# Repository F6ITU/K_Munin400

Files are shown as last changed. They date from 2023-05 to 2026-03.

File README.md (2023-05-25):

# K_Munin400
LA2NI's OpenHPSDR 400W HF amplifier (Kicad Version)

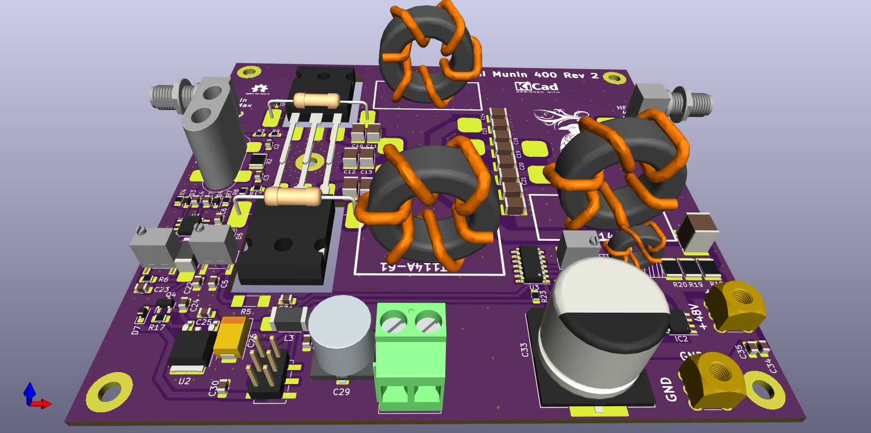
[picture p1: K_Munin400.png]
Munin, a 400W HF linear amplifier


This amplifier board is part of a set consisting of a 400 W LD-Mos based RF power amplifier (Munin 400), 
a medium power Zolotarev low pass filter (600 or 1500 W), an Automatic Antenna Tuner (ATU) nickname « Aries » 
and a 4 port antenna switch.

All these developments are the work and intellectual property of Kjell Karlsen LA2NI and Laurence Barker G8NJJ.

This original work can be downloaded from

https://github.com/LA2NI/

https://github.com/laurencebarker

This board was originally developed in December 2021 by Kjell LA2NI , with UltiBoard EDA. This repository is a « bug for bug »
clone of the original amplifier using the Opensource Kicad EDA. 
All these KiCad files are, consequently, the intellectual property of Kjell LA2NI.

This portage (convertion/translation) is placed under the CERN Open source/ Open hardware Licence.

Kicad is an Opensource EDA software maintained by the European Reseach Center CERN (Conseil européen pour la recherche nucléaire)

The original work is protected by the TAPR Open Hardware licence

Munin and Hugin are the two "messenger" ravens of the Norse god Odin - just as Hermes is the messenger-god in Greek mythology, 
and the masterpiece of the OpenHPSDR architecture 

This LDMoS transistor-based amplifier brings speech over the great distances of the "Midgard" of the waves

# Work in progress
do NOT use these files as long as this footnote hasn't been deleted

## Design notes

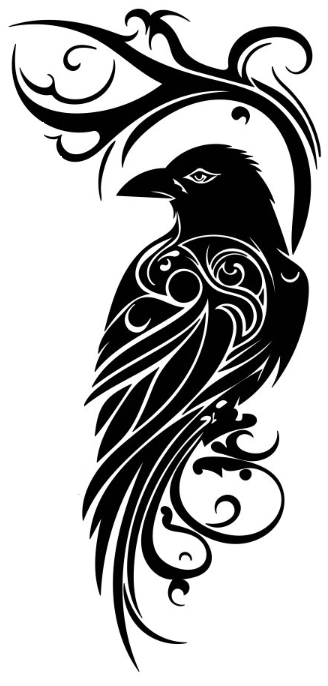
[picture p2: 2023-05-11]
Documentation/munin.bmp

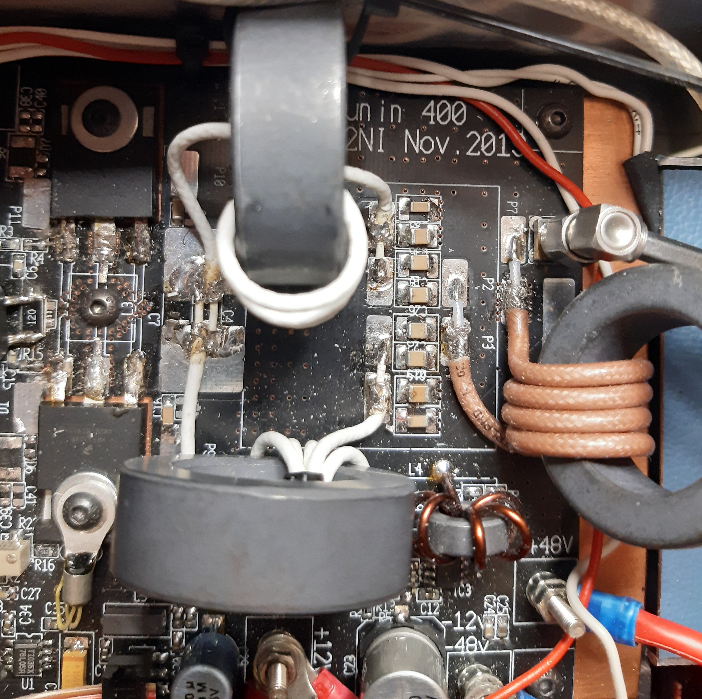
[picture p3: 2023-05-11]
Documentation/Ampli_kjell1.jpg

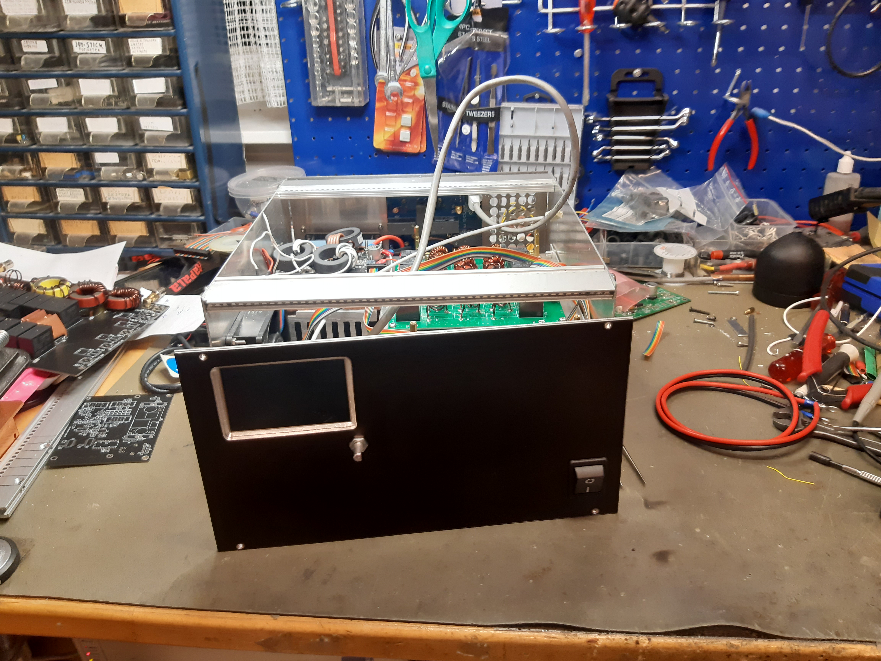
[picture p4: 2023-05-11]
Documentation/Ampli_kjell_2.jpg

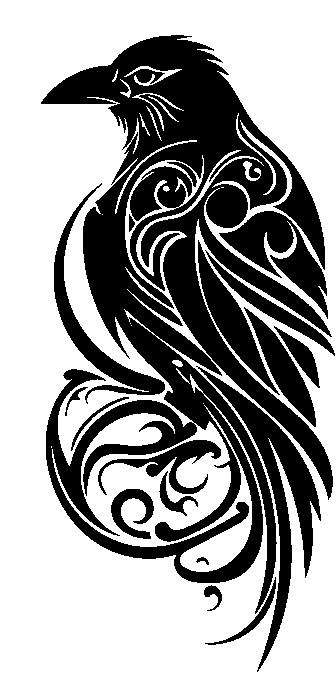
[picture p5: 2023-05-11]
Documentation/hugin.bmp

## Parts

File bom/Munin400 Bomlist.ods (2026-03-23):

Composant | Valeur | Taille | Référence Mouser | Référence Farnell | Référence RS | Référence TME
C1, C2, C12, C13, C17, C32, C34, C35 | 1μ | 0805 | 963-MJ212DC7105MGHTE | 1414042 | 192-7661
C10, C11, C19, C5, C27, C30, C31 | 100nf | 0805 |  | 1833888 | 264-4416
C14 | 22μ/63V |  | 81-KRM55WR71J226MH1K | 1850125
C18, C19, C22, C26 | 100nf haute bourre | 1812 | 810-C4532C0G2E104KKN | délais longs | 169-6642
C23 | 330μ /63V |  | 594-MAL214699809E3 | 3265775
C24, C32 | 1μ/100V | 0805 | 963-MJ212DC7105MGHTE | pas trouvé en 0805
C25 | 100nf/100V | 0805 | 581-FS051C104K4Z2A | 1907331
C28 | 10μ/35V | 2220 | 581-2220DC106MAT2A | 9697012
C29 | 220μ/25V |  | 661-HHXF250ARA221MHA | 1834209
C3, C16 | 10nf/250V | 1210
C33, C36, C20, C21 | 100nf décloupage transfos | 1812 | 810-C4532C0G2E104KKN
C6, C15, C37 | 10nf | 0805
C9, C42 | 1μ/250v | 0805
D1, D2, D5 | BAS16J |  | 771-BAS16J115 | délais longs | 166-0036 en rupture
D7, D6 | CDSOD323-TC03
D8 | CDSOD323-TC15C
IC1 | LM358N |  | 926-LM358AMX/NOPB
IC3 | ACHS-7123
J2, J8 | SMA femelle
L4 | Tore 61 |  | Rota Franco
L7, L5 | 27430211447 |  | 623-2743021447LF
R1, R22 | Potar 10k |  | TS53YJ 10K 20%TR
R12, R21 | 220R | 1206
R13, R25 | 10k | 0805 |  |  | 565-948
R14 | NTC 10K |  | 594-NTCALUG02A103F
R16 | 6k8 |  |  |  | 666-2584
R18, R19, R20 | 4R7 | 1206 |  |  | 721-8655
R2 | 1k2 | 0805 |  |  | 662-0455
R23 | potar 1K
R24 | 100 R | 0805 |  |  | pas dispo
R3, R17 | 22R | 0805 |  |  | pas dispo
R4, R15 | 1R | 0805
R5 | 27k | 0805
R7, R9, R10, R11, R26, R27 | 470/3W
R8 | 5R6 | 1812
T4, T5, T6 | FT-114U-61-A |  | compat. Fair-Rite 5961001201 | 5961001201 | 5961001201 mouser
TR1 | MRF300AN |  | 771-MRF300AN
TR2 | MRF300BN |  | 771-MRF300BN
TR3 | BSS84 |  |  |  | 166-0053
U1 | 78L05 |  | 595-UA78L05CDRE4 à vérifier brochage |  | 688-9313
U2 | LMC660 |  | longs délais | longs délais dispo chez Reichelt | 460-572 | LMC660AIM/NOPB
SMA femelle coudée |  |  |  |  | 878-2413
Connecteur J3 |  |  | 855-M20-8760342R
 | 01/23

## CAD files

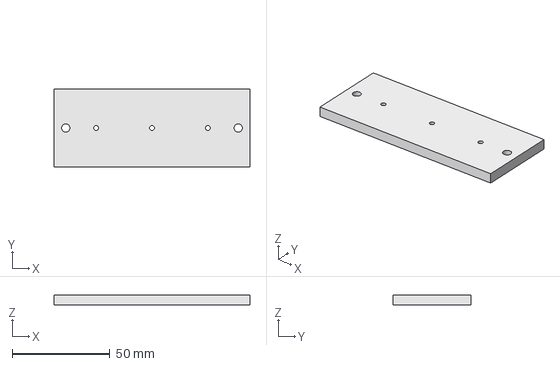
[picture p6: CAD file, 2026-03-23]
Documentation/copper_heat_spreader.FCStd
100.0 x 40.0 x 5.00 mm

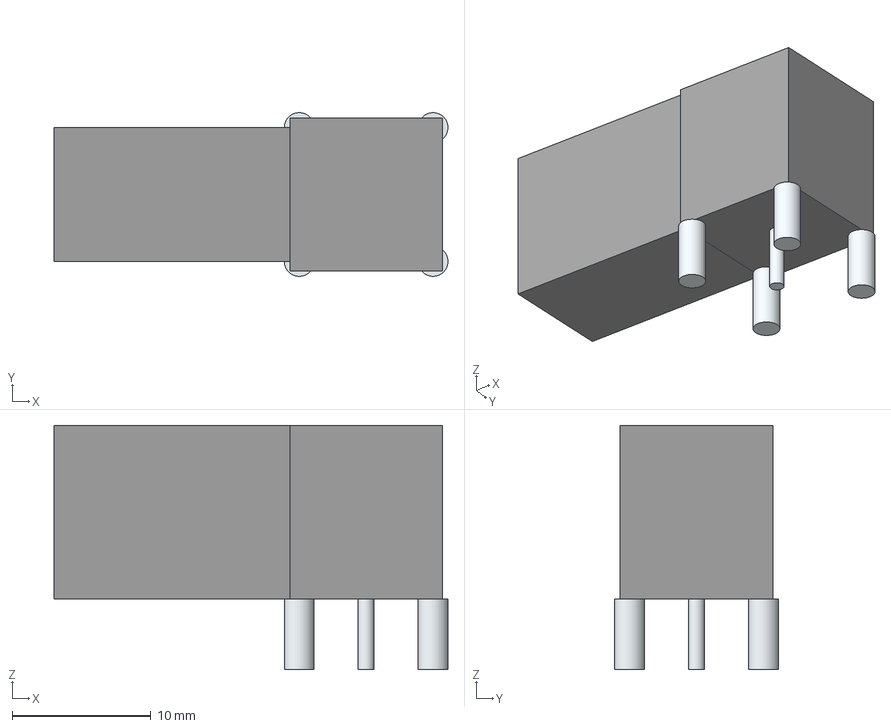
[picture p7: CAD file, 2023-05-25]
Documentation/TNC PCB/73204-5213/3D/73204-5213.stp
28.4 x 11.8 x 17.6 mm
Leads x 5

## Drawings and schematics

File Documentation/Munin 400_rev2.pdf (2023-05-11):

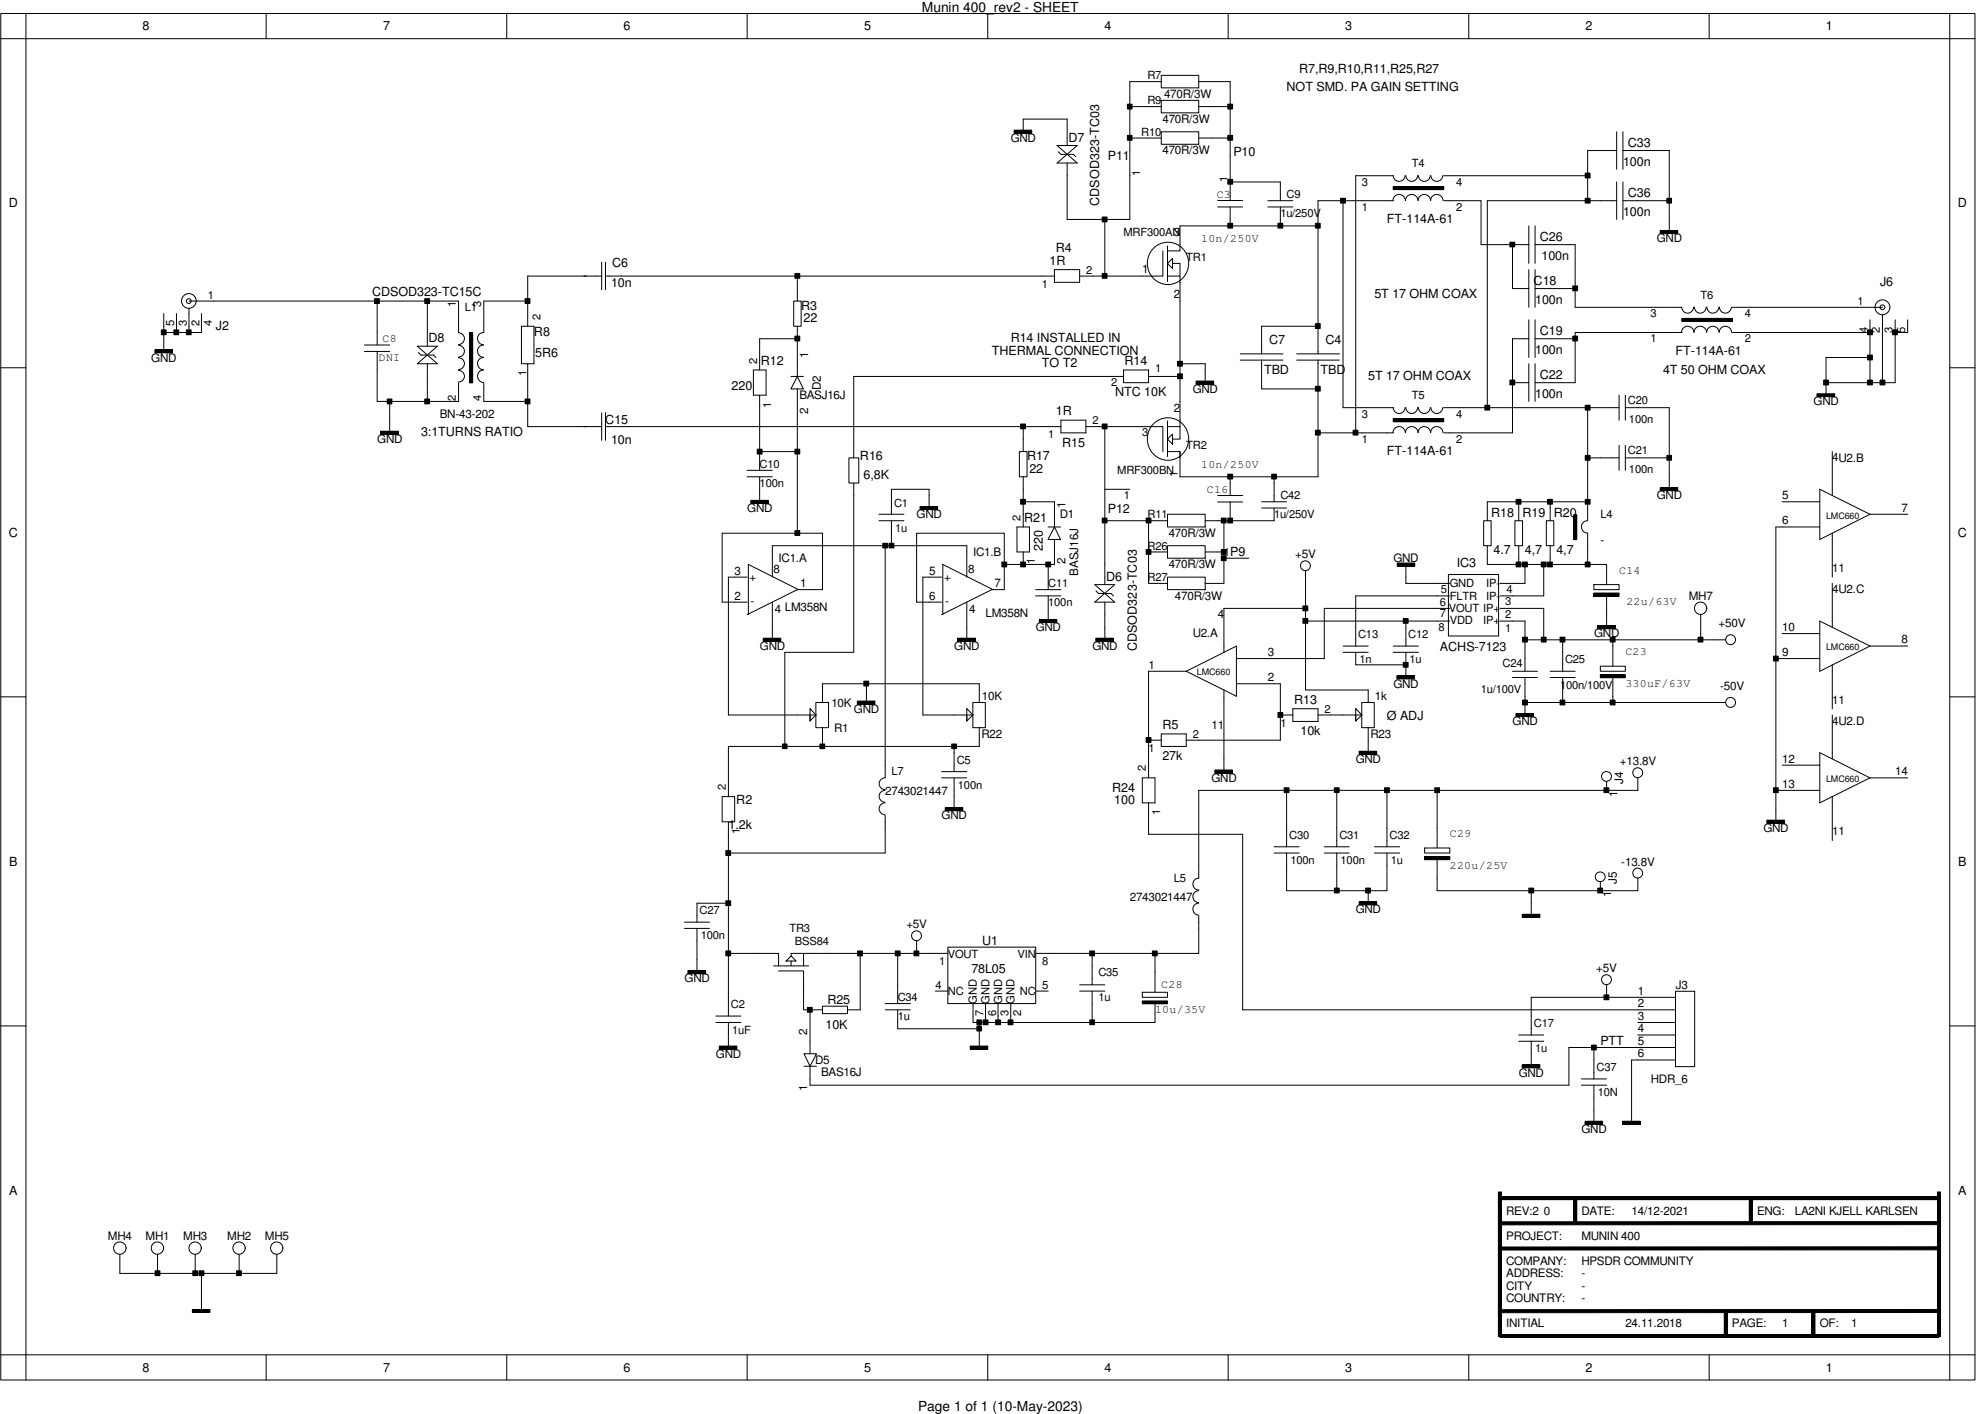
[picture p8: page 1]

NOT SMD. PA GAIN SETTING

1 IP+ 2 IP+ 3 IP- 4 IP- 5 GND 6 FLTR 7 VOUT 8 VDD

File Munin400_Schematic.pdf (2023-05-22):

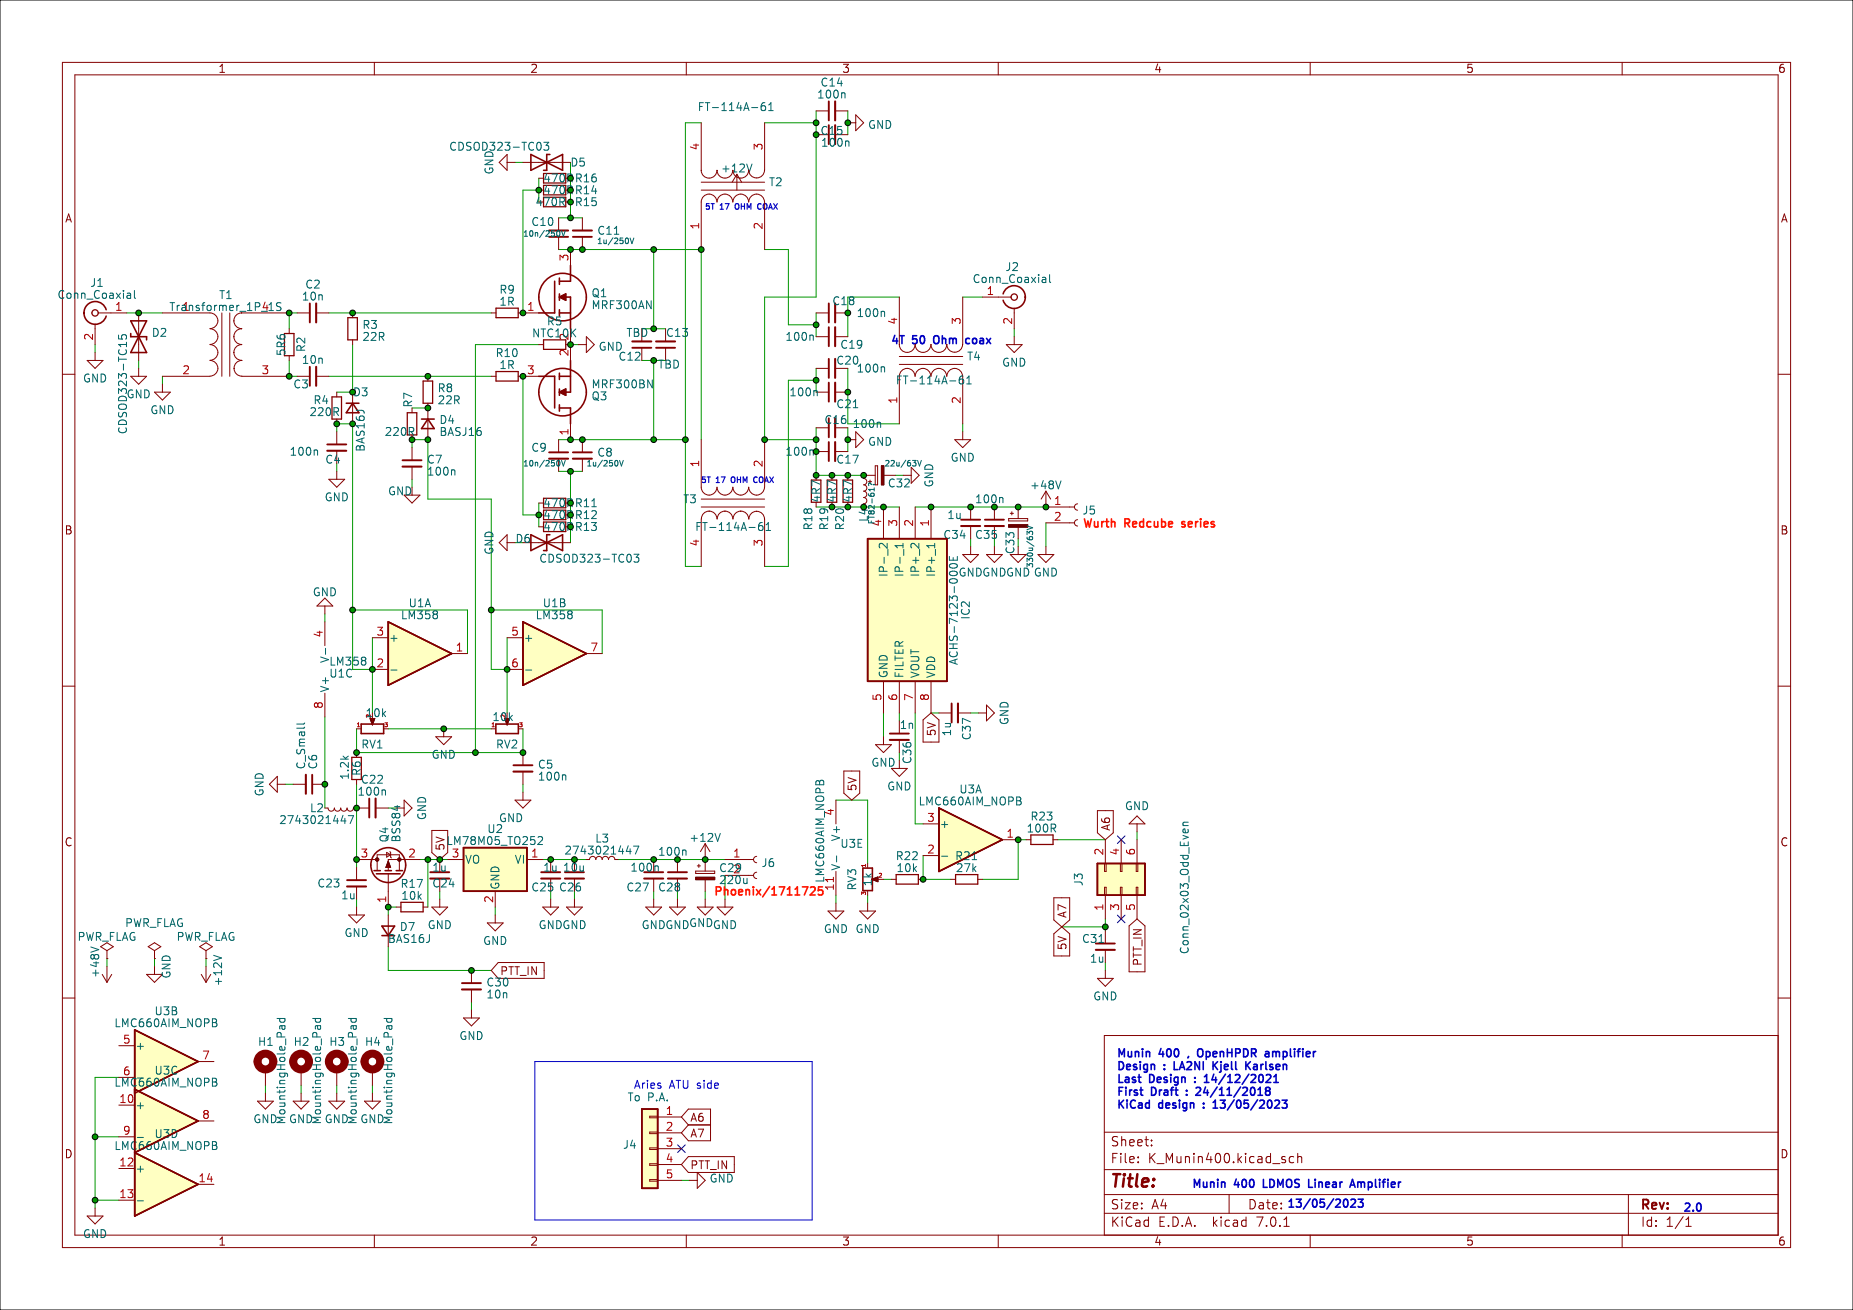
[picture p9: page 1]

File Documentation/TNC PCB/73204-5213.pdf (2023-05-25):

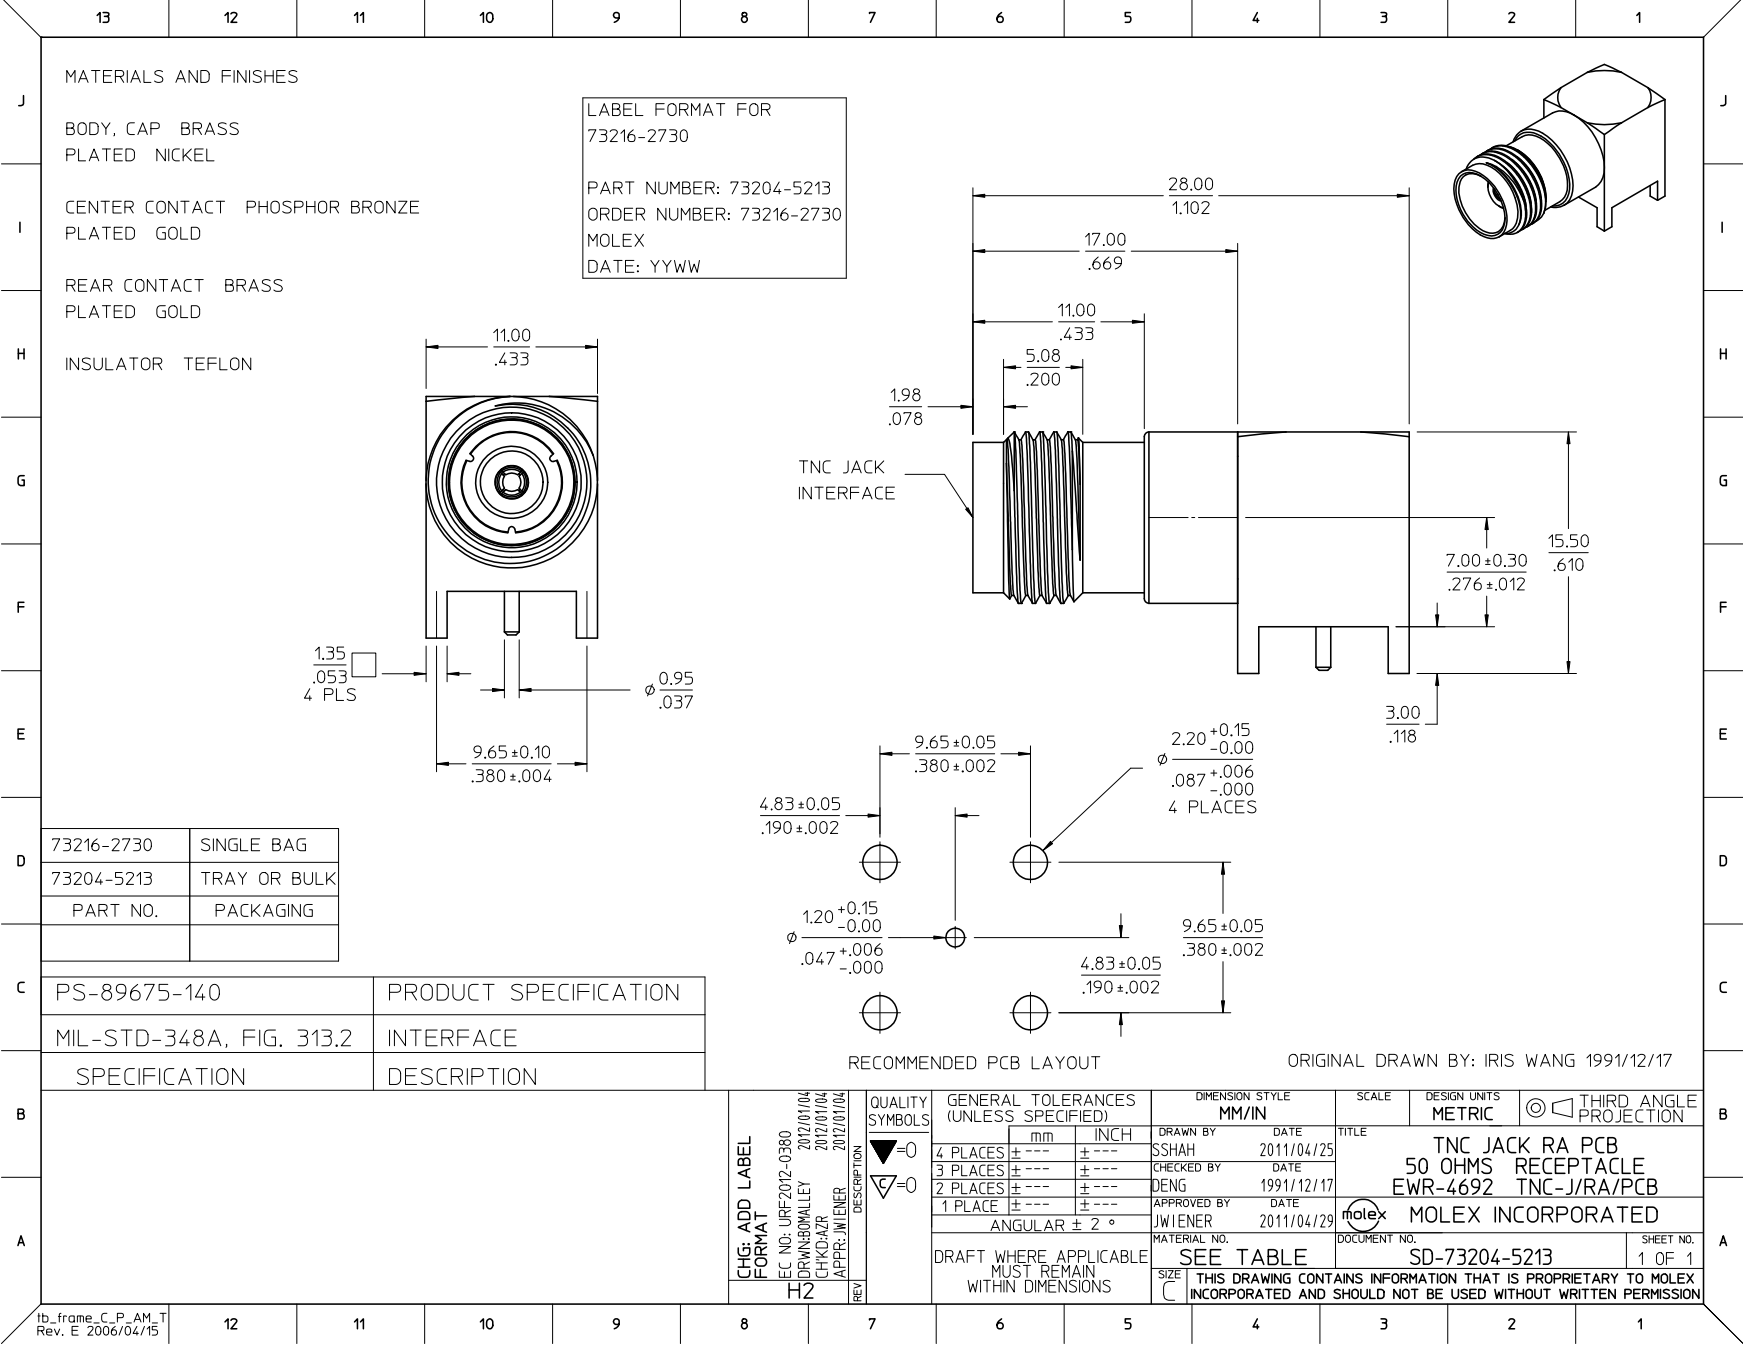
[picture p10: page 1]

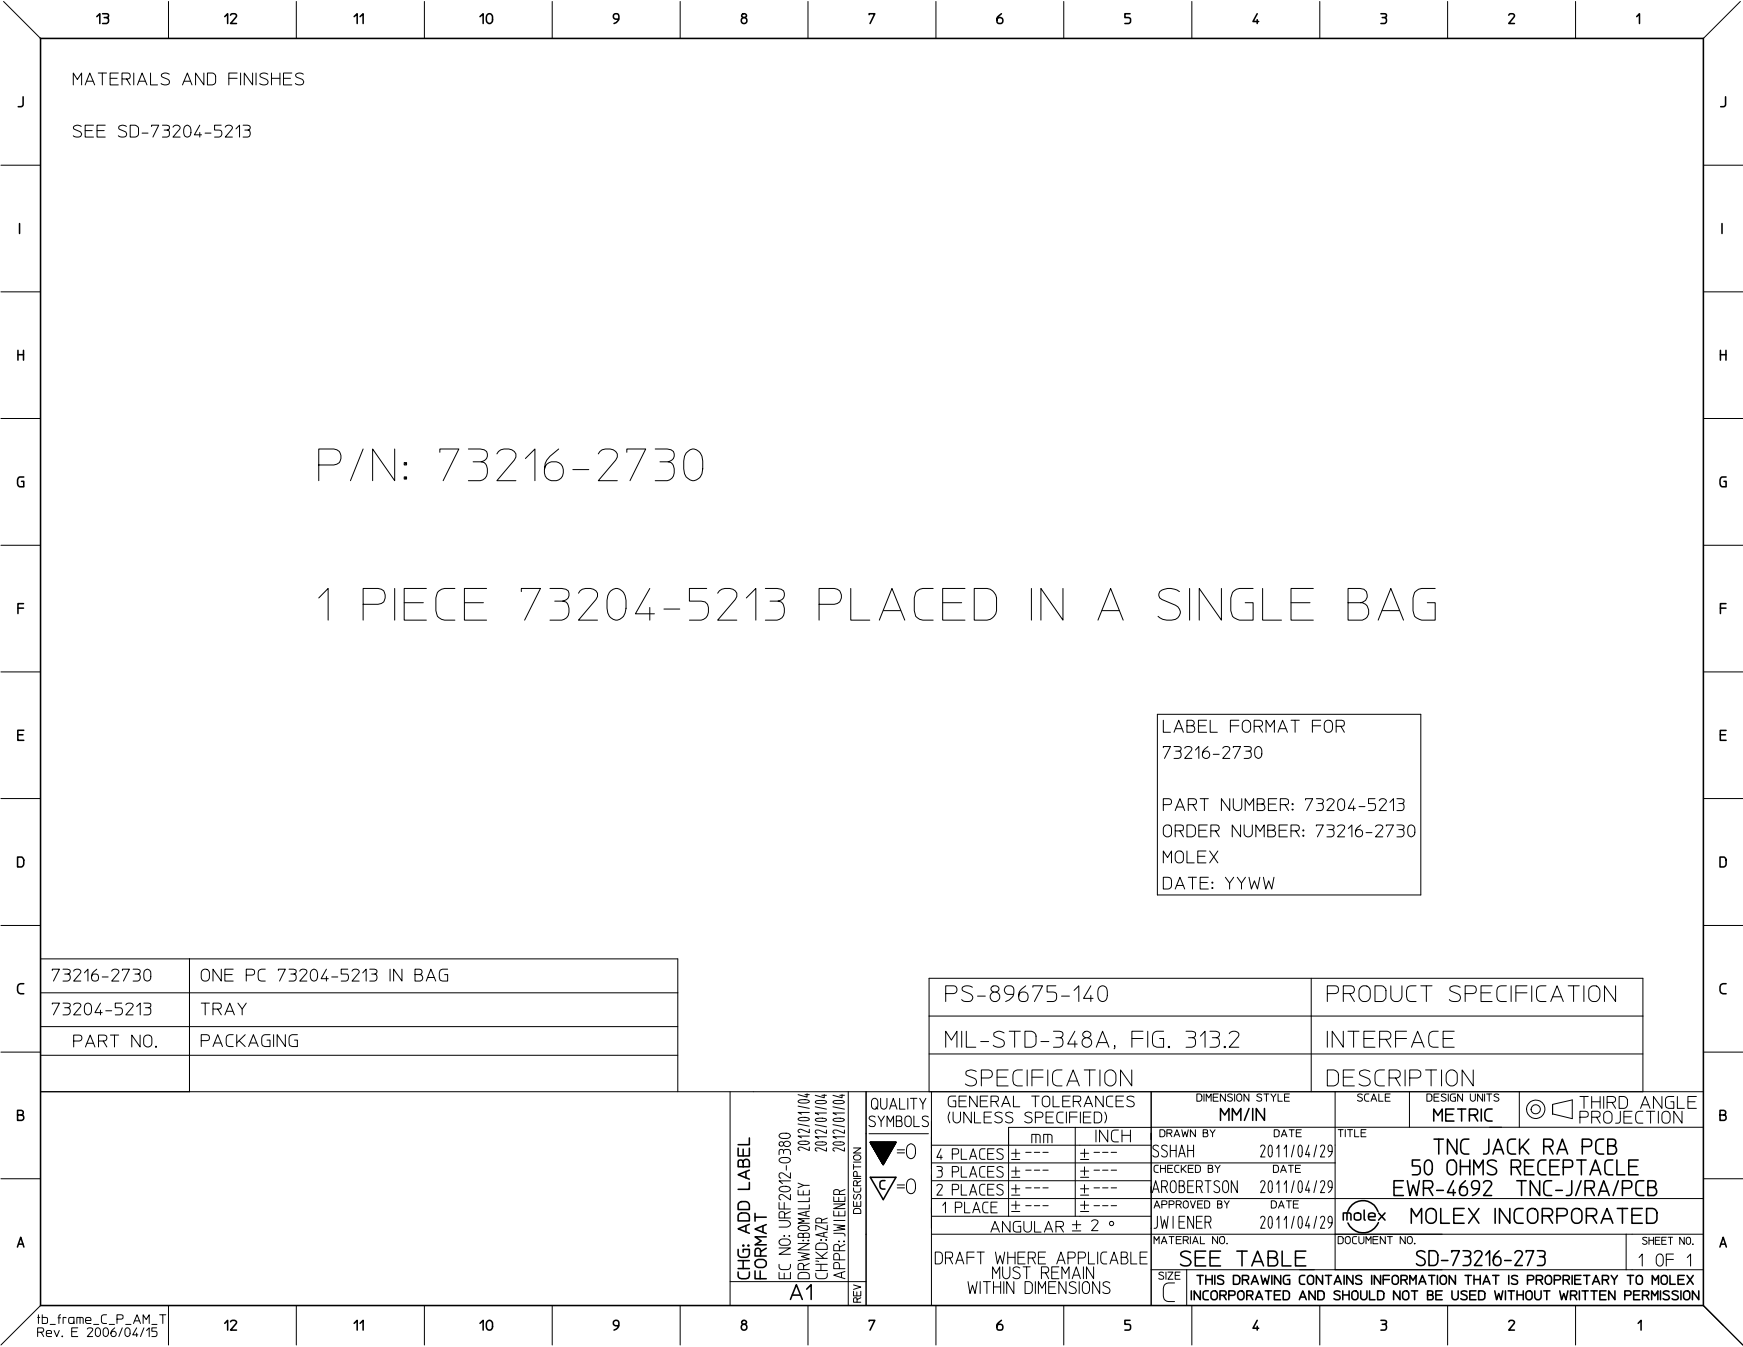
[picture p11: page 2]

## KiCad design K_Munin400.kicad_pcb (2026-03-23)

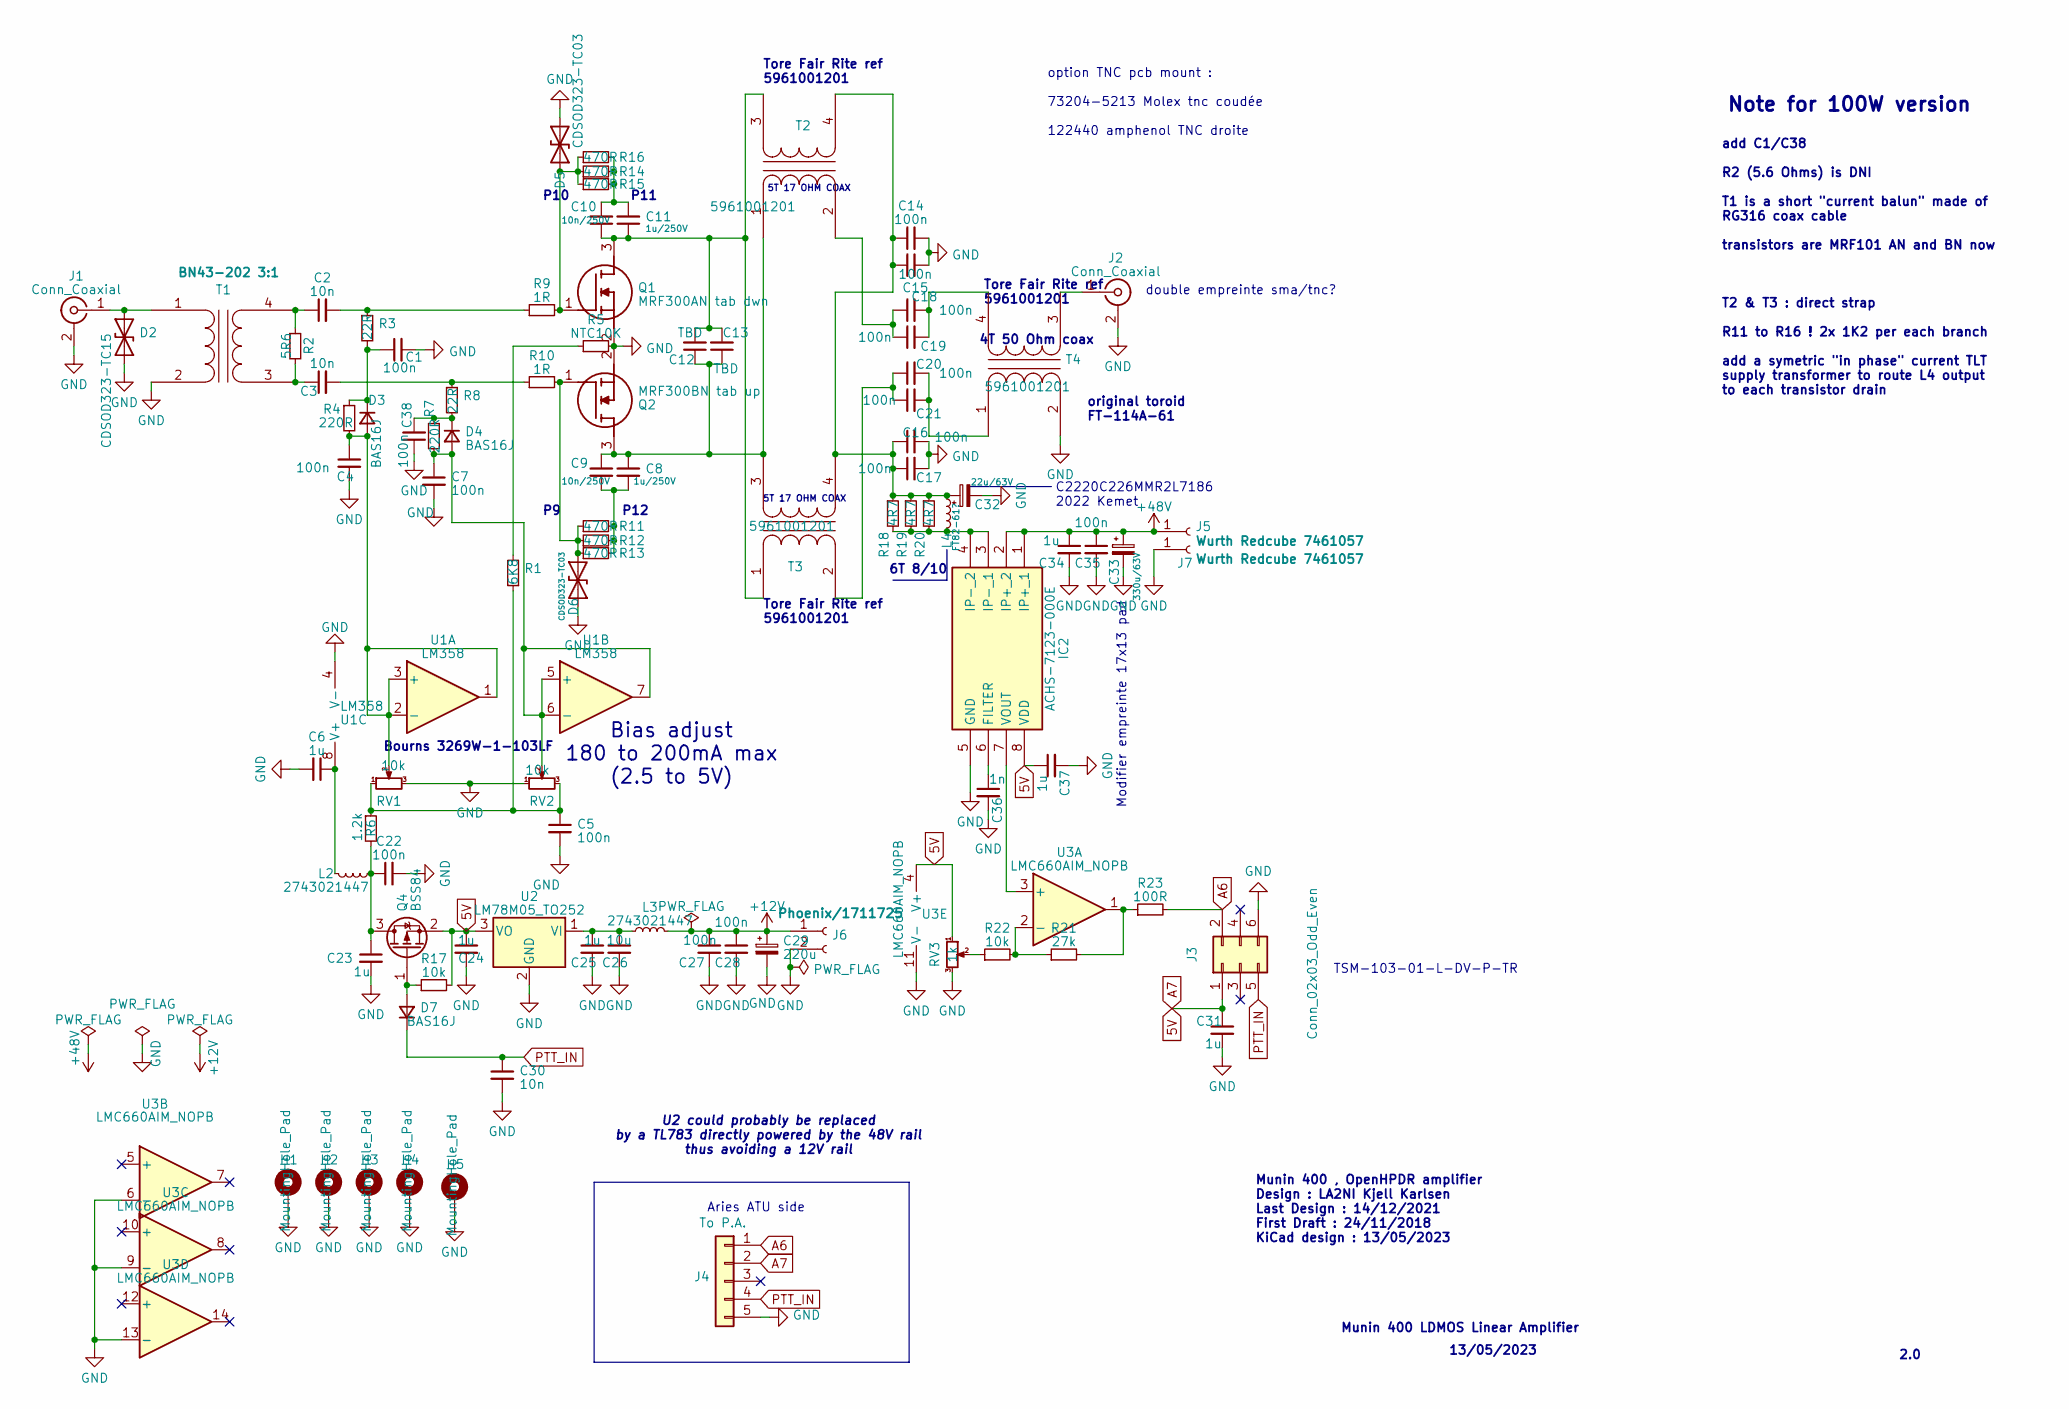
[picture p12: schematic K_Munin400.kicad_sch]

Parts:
C1, C38: 100n; C_0805_2012Metric
C2, C3, C30: 10n; C_0805_2012Metric_Pad1.18x1.45mm_HandSolder
C4, C5, C7, C22, C27, C28, C35: 100n; C_0805_2012Metric_Pad1.18x1.45mm_HandSolder
C6, C23, C24, C25, C31, C34, C37: 1u; C_0805_2012Metric_Pad1.18x1.45mm_HandSolder
C8, C11: 1u/250V; C_1812_4532Metric_Pad1.57x3.40mm_HandSolder
C9, C10: 10n/250V; C_1812_4532Metric_Pad1.57x3.40mm_HandSolder
C12, C13: TBD; C_1812_4532Metric_Pad1.57x3.40mm_HandSolder
C14, C15, C16, C17, C18, C19, C20, C21: 100n; C_1812_4532Metric_Pad1.57x3.40mm_HandSolder
C26: 10u; CP_EIA-7343-31_Kemet-D_Pad2.25x2.55mm_HandSolder
C29: 220u; C_Elec_8x10.2
C32: 22u/63V; C_2220_5650Metric_Pad1.97x5.40mm_HandSolder
C33: 330u/63V; CP_Elec_18x17.5
C36: 1n; C_0805_2012Metric_Pad1.18x1.45mm_HandSolder
D2: CDSOD323-TC15; D_SOD-323_HandSoldering
D3, D4, D7: BAS16J; D_SOD-323_HandSoldering
D5, D6: CDSOD323-TC03; D_SOD-323_HandSoldering
H1, H2, H3, H4, H5: MountingHole_Pad; MountingHole_3.5mm_Pad_TopBottom
IC2: ACHS-7123-000E; SOIC-8_3.9x4.9mm_P1.27mm; Mouser Part Number 630-ACHS-7123-000E
J1, J2: Conn_Coaxial; SMA_PINS
J3: Conn_02x03_Odd_Even; IDC-Header_2x03_P2.54mm_Vertical_SMD
J4: To P.A.; Molex_KK-254_AE-6410-05A_1x05_P2.54mm_Vertical
J5, J7: Wurth Redcube 7461057; 7461057
J6: Phoenix/1711725; 1711725
L2, L3: 2743021447; Fair-Rite_2743021447
L4: FT82-61?; T50_V_smd
Q1: MRF300AN tab dwn; TO-247-3_Horizontal_TabDown; Mouser Part Number 771-MRF300AN
Q2: MRF300BN tab up; TO-247-3_Horizontal_TabUp; Mouser Part Number 771-MRF300AN
Q4: BSS84; SOT-23
R1: 6K8; R_0805_2012Metric_Pad1.20x1.40mm_HandSolder
R2: 5R6; R_1812_4532Metric_Pad1.30x3.40mm_HandSolder
R3, R8: 22R; R_0805_2012Metric_Pad1.20x1.40mm_HandSolder
R4, R7: 220R; R_0805_2012Metric_Pad1.20x1.40mm_HandSolder
R5: NTC10K; R_MELF_MMB-0207
R6: 1.2k; R_0805_2012Metric_Pad1.20x1.40mm_HandSolder
R9, R10: 1R; R_0805_2012Metric_Pad1.20x1.40mm_HandSolder
R11, R12, R13, R14, R15, R16: 470R; R_Axial_DIN0414_L11.9mm_D4.5mm_P25.40mm_Horizontal
R17, R22: 10k; R_0805_2012Metric_Pad1.20x1.40mm_HandSolder
R18, R19, R20: 4R7; R_1812_4532Metric_Pad1.30x3.40mm_HandSolder
R21: 27k; R_0805_2012Metric_Pad1.20x1.40mm_HandSolder
R23: 100R; R_0805_2012Metric_Pad1.20x1.40mm_HandSolder
RV1, RV2: 10k; Potentiometer_Bourns_3269W_Vertical
RV3: 1k; Potentiometer_Bourns_3269W_Vertical
T1: BN43-202 3:1; BN43-202
T2: 5961001201; FT114A-61
T3: 5961001201; FT114A-61_B
T4: 5961001201; FT114A-61_out
U1: LM358; SOIC-8_3.9x4.9mm_P1.27mm
U2: LM78M05_TO252; TO-252-2
U3: LMC660AIM_NOPB; SOIC-14_3.9x8.7mm_P1.27mm

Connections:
5V: C24.1, C31.1, C37.1, IC2.8 (VDD), J3.1, J4.2, Q4.2 (S), R17.2, RV3.1, U2.3 (VO), U3.4 (V+)
+12V: C27.1, C28.1, C29.1, J6.1, L3.1
+48V: C33.1, C34.1, C35.1, IC2.1 (IP+_1), IC2.2 (IP+_2), J5.1
A6: J3.2, J4.1, R23.2
GND: C1.2, C4.2, C5.2, C6.2, C7.2, C14.2, C15.2, C16.2, C17.2, C22.2, C23.2, C24.2, C25.2, C26.2, C27.2, C28.2, C29.2, C30.2, C31.2, C32.2, C33.2, C34.2, C35.2, C36.2, C37.2, C38.1, D2.1 (A1), D5.1 (A1), D6.2 (A2), H1.1, H2.1, H3.1, H4.1, H5.1, IC2.5 (GND), J1.2 (Ext), J2.2 (Ext), J3.6, J4.5, J6.2, J7.1, Q1.2 (S), Q2.2 (S), R5.2, RV1.3, RV2.1, RV3.3, T1.2 (AB), T4.2 (AB), U1.4 (V-), U2.2 (GND), U3.6 (-), U3.9 (-), U3.11 (V-), U3.13 (-)
unnamed: C2.2, R3.1, R9.1
unnamed: C3.2, R8.1, R10.1
unnamed: C5.1, R1.1, R6.1, RV1.1, RV2.3
unnamed: C8.2, C9.2, R11.2, R12.2, R13.2
unnamed: C10.2, C11.2, R14.2, R15.2, R16.2
unnamed: D2.2 (A2), J1.1 (In), T1.1 (AA)
unnamed: C4.1, D3.2 (A), R4.2, RV1.2, U1.1, U1.2 (-), U1.3 (+)
unnamed: C1.1, D3.1 (K), R3.2, R4.1
unnamed: C7.1, D4.2 (A), R7.2, RV2.2, U1.5 (+), U1.6 (-), U1.7
unnamed: C38.2, D4.1 (K), R7.1, R8.2
unnamed: D5.2 (A2), Q1.1 (G), R9.2, R14.1, R15.1, R16.1
unnamed: D6.1 (A1), Q2.1 (G), R10.2, R11.1, R12.1, R13.1
unnamed: D7.2 (A), Q4.1 (G), R17.1
unnamed: C36.1, IC2.6 (FILTER)
unnamed: IC2.3 (IP-_1), IC2.4 (IP-_2), L4.1, R18.2, R19.2, R20.2
unnamed: IC2.7 (VOUT), U3.3 (+)
unnamed: J2.1 (In), T4.3 (SA)
unnamed: C10.1, C11.1, C12.2, C13.2, Q1.3 (D), T2.3 (SB), T3.1 (AA)
unnamed: C8.1, C9.1, C12.1, C13.1, Q2.3 (D), T2.1 (AA), T3.3 (SB)
unnamed: C22.1, C23.1, L2.2, Q4.3 (D), R6.2
unnamed: R1.2, R5.1
unnamed: R21.2, R23.1, U3.1
unnamed: R22.1, RV3.2
unnamed: C3.1, R2.2, T1.3 (SA)
unnamed: C2.1, R2.1, T1.4 (SB)
unnamed: C18.1, C19.1, T2.2 (AB)
unnamed: C14.1, C15.1, C16.1, C17.1, C32.1, L4.2, R18.1, R19.1, R20.1, T2.4 (SA), T3.4 (SA)
unnamed: C20.1, C21.1, T3.2 (AB)
unnamed: C20.2, C21.2, T4.1 (AA)
unnamed: C18.2, C19.2, T4.4 (SB)
unnamed: C6.1, L2.1, U1.8 (V+)
unnamed: C25.1, C26.1, L3.2, U2.1 (VI)
unnamed: R21.1, R22.2, U3.2 (-)
PTT_IN: C30.1, D7.1 (K), J3.5, J4.4

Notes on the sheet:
5T 17 OHM COAX
Note for 100W version
Modifier empreinte 17x13 pad
Aries ATU side
13/05/2023
Munin 400 , OpenHPDR amplifier Design : LA2NI Kjell Karlsen Last Design : 14/12/2021 First Draft : 24/11/2018 KiCad design : 13/05/2023
2.0
TSM-103-01-L-DV-P-TR
Bourns 3269W-1-103LF
Munin 400 LDMOS Linear Amplifier
P9 P12
U2 could probably be replaced by a TL783 directly powered by the 48V rail thus avoiding a 12V rail
6T 8/10
Tore Fair Rite ref 5961001201
option TNC pcb mount : 73204-5213 Molex tnc coudée 122440 amphenol TNC droite
Bias adjust 180 to 200mA max (2.5 to 5V)
P10 P11
double empreinte sma/tnc?
4T 50 Ohm coax
original toroid FT-114A-61
add C1/C38 R2 (5.6 Ohms) is DNI T1 is a short "current balun" made of RG316 coax cable transistors are MRF101 AN and BN now T2 & T3 : direct strap R11 to R16 ! 2x 1K2 per each branch add a symetric "in phase" current TLT supply transformer to route L4 output to each transistor drain
C2220C226MMR2L7186 2022 Kemet

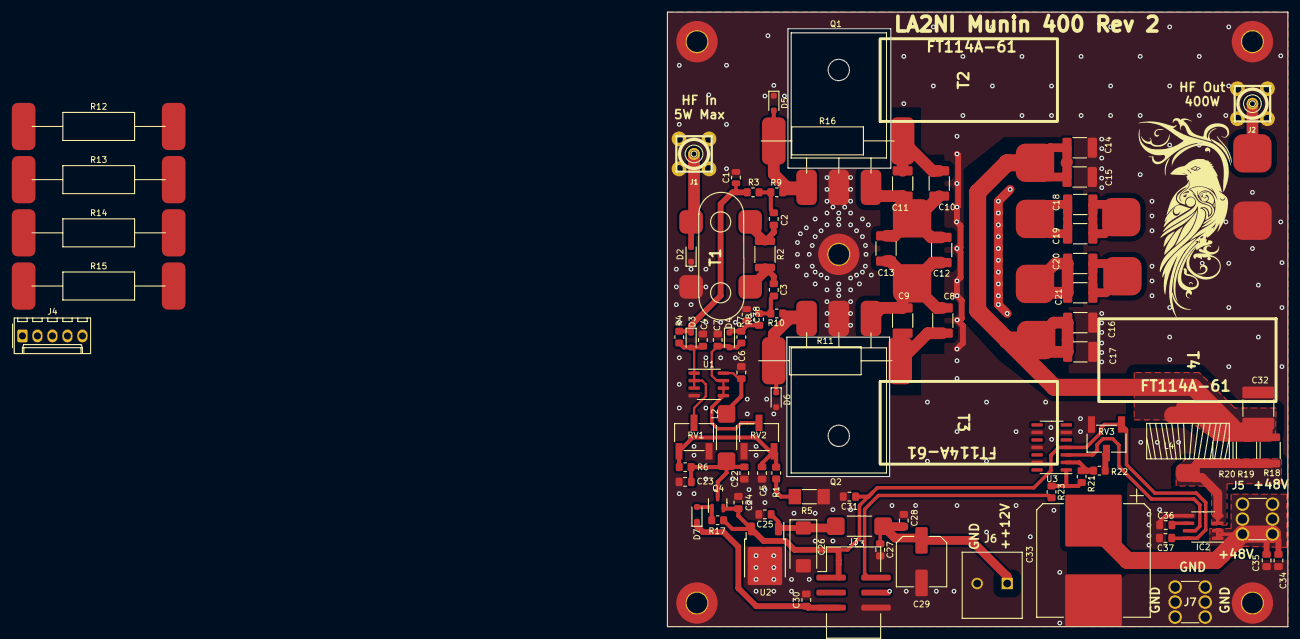
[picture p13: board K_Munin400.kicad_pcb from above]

Board: 2 copper layers, 105.0 x 104.0 mm, 96 parts (0 on the bottom side), 39 nets.

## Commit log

2023-05-11 first commit, repository creation
    [K_Munin400.kicad_pcb, K_Munin400.kicad_sch]
2023-05-12 schematic early stage
    [K_Munin400.kicad_sch]
2023-05-13 schematic completed, footprints not yet defined
    [K_Munin400.kicad_sch]
2023-05-13 schematic completed, footprint not yet configured
    [K_Munin400.kicad_sch]
2023-05-22 all footprint and 3D module defined, schematic completed
    [K_Munin400.kicad_pcb, K_Munin400.kicad_sch]
2023-05-23 3Dshapes set
    [K_Munin400.kicad_pcb, K_Munin400.kicad_sch]
2023-05-25 some debuging, new placement, silk logo
    [73204-5213.stp, K_Munin400.kicad_pcb, K_Munin400.kicad_sch]
2023-05-25 placement and routing completed
    [K_Munin400.kicad_pcb, K_Munin400.kicad_sch]
2023-05-25 new gerber, small pcb mods
    [K_Munin400-B_Cu.gbr, K_Munin400-B_Mask.gbr, K_Munin400-B_Paste.gbr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]
2026-03-23 kicad 10 update, minor schematic changes
    [K_Munin400-B_Cu.gbr, K_Munin400-B_Mask.gbr, K_Munin400-B_Paste.gbr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]
